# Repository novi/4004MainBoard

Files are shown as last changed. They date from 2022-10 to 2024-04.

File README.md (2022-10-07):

[周辺回路(ROM, IO)](https://github.com/novi/4004Peripheral)

TODO:

* たまにリセットが効かないことがある(手動リセットすること)
* バッファドライバの改善

## See Also

* [jim11662418/4004-SBC](https://github.com/jim11662418/4004-SBC)
* [MCS-4 Test Boards for Sale](https://www.cpushack.com/mcs-4-test-boards-for-sale/)
* [Intel 4004 — 50th Anniversary Project](https://www.4004.com)
* [Intel 4004 system](http://dangerousprototypes.com/forum/index.php?topic=4721.0)
* [MCS-4](http://www.st.rim.or.jp/~nkomatsu/intel4bit/i4004.html)
* [佐野正博「世界最初のマイクロプロセッサ Intel 4004」](https://www.sanosemi.com/document/Intel_4004_Ver4-2.pdf)
* [Intel 4004の回路図を読む](http://www.gc-net.jp/omiokone/mcs4/index.htm)
* [マイクロプロセッサ 4004 の開発](https://www.shmj.or.jp/dev_story/pdf/develop43.pdf)

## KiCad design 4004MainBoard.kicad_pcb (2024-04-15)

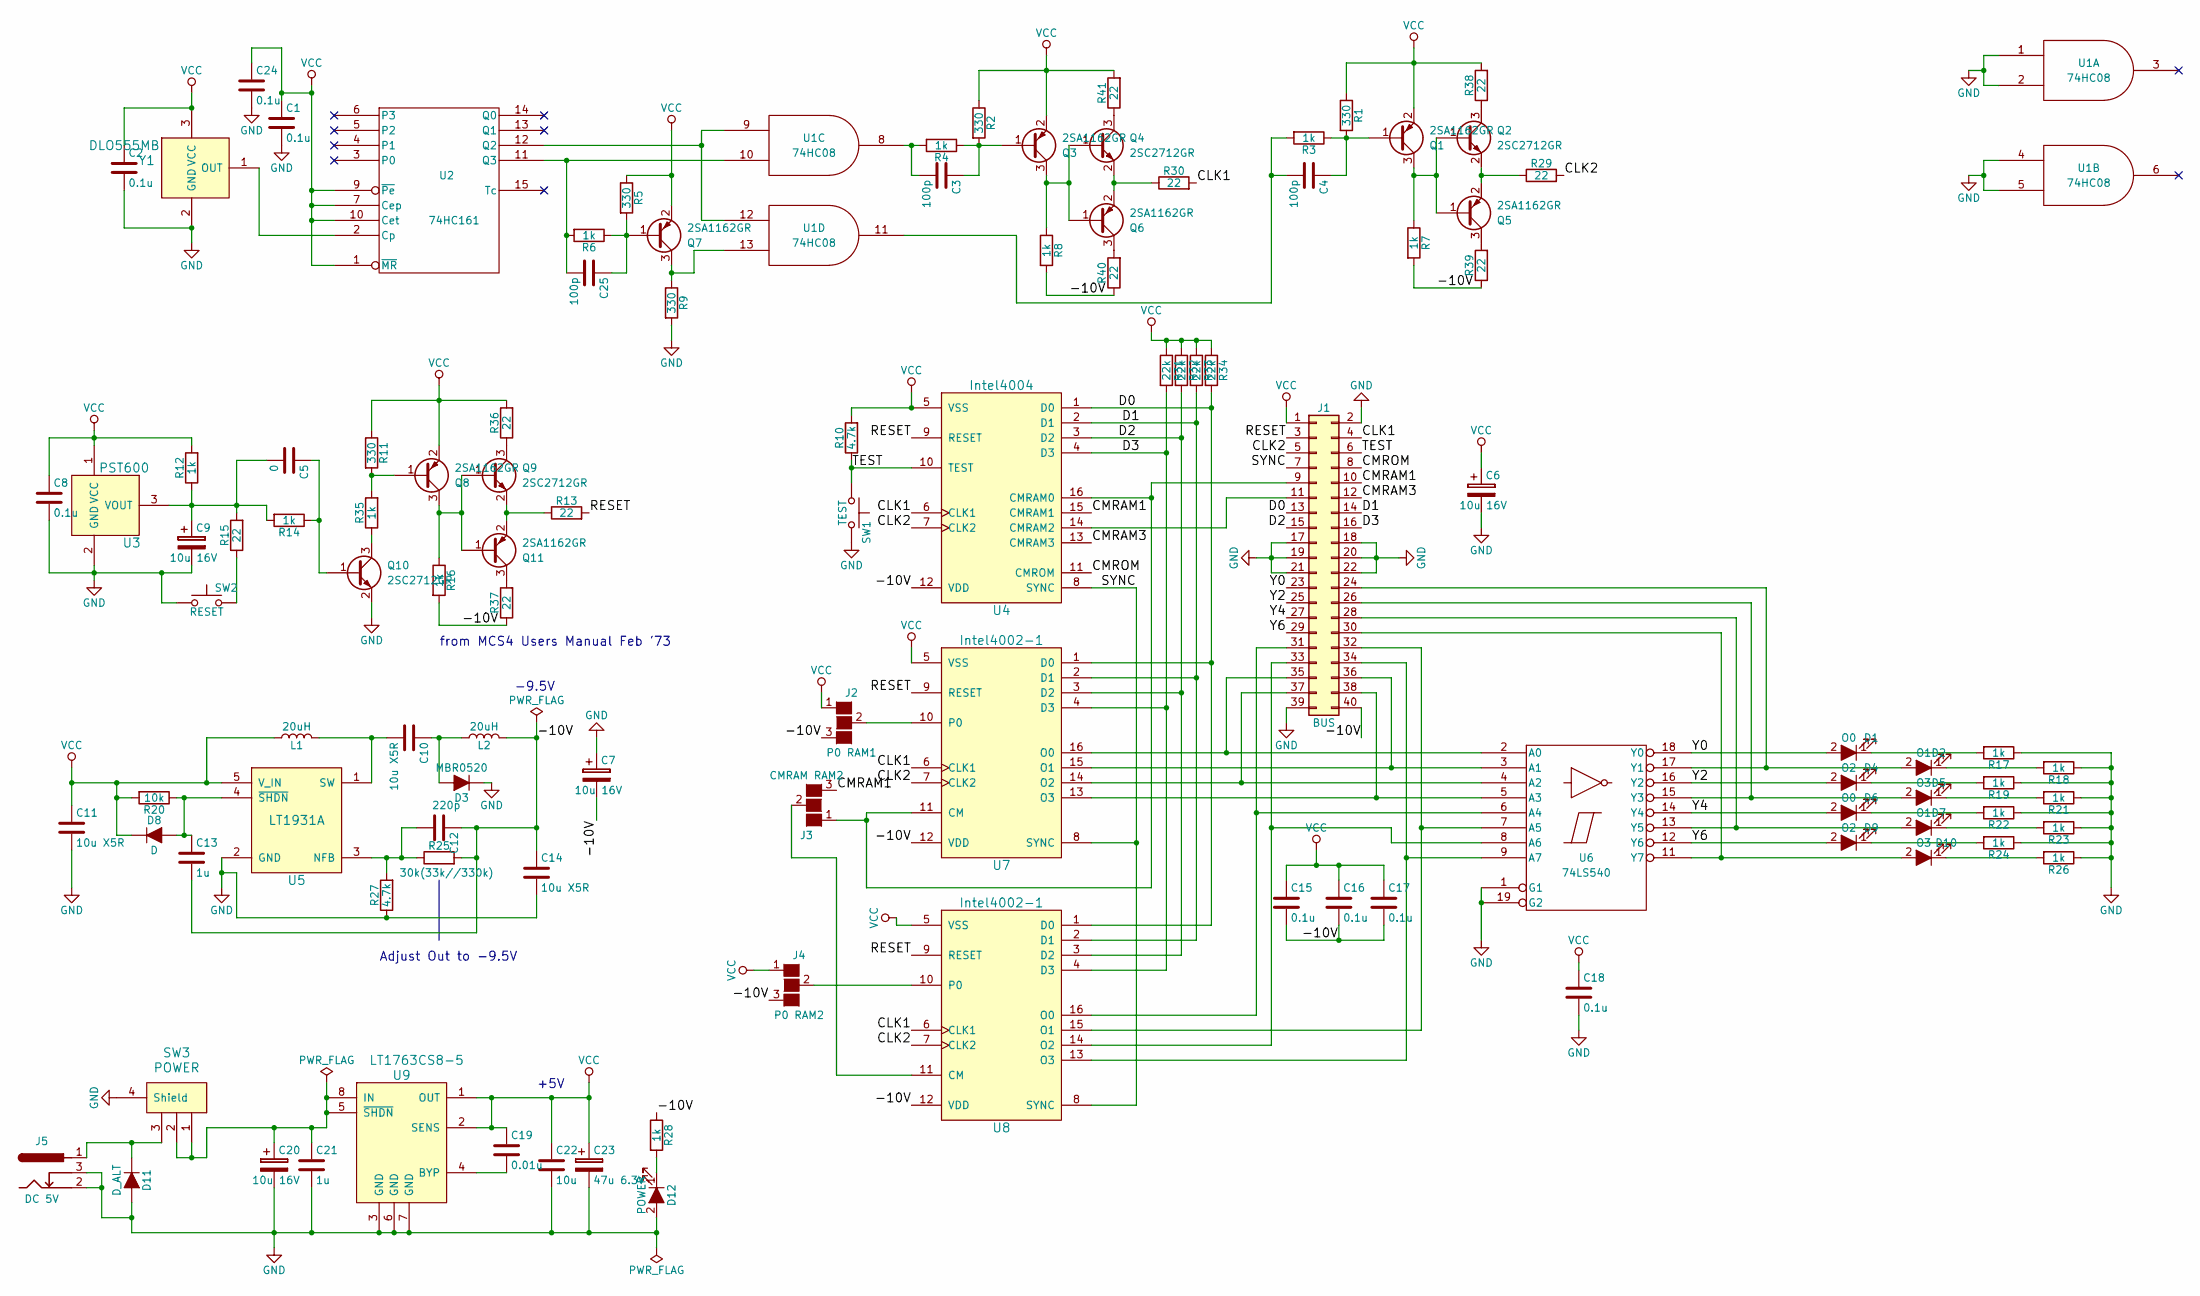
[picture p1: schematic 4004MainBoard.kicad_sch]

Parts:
C1, C2, C8, C15, C16, C17, C18, C24: 0.1u; C_0603_1608Metric_Pad1.08x0.95mm_HandSolder
C3, C4, C25: 100p; C_0603_1608Metric_Pad1.08x0.95mm_HandSolder
C5: 0; C_0603_1608Metric_Pad1.08x0.95mm_HandSolder
C6, C7, C9, C20: 10u 16V; CP_Elec_4x4.5
C10, C11, C14: 10u X5R; C_1206_HandSoldering
C12: 220p; C_0603_1608Metric_Pad1.08x0.95mm_HandSolder
C13, C21: 1u; C_0603_1608Metric_Pad1.08x0.95mm_HandSolder
C19: 0.01u; C_0603_1608Metric_Pad1.08x0.95mm_HandSolder
C22: 10u; C_1206_HandSoldering
C23: 47u 6.3V; CP_Elec_5x5.8
D1, D6: O0; LED_0603_HandSoldering
D2, D7: O1; LED_0603_HandSoldering
D3: MBR0520; D_SOD-123_HandSoldering
D4, D9: O2; LED_0603_HandSoldering
D5, D10: O3; LED_0603_HandSoldering
D8: D; D_SOD-123_HandSoldering
D11: D_ALT; D_SOD-123_HandSoldering
D12: POWER; LED_0603_HandSoldering
J1: BUS; Pin_Header_Straight_2x20_Pitch2.54mm
J2: P0 RAM1; GS3
J3: CMRAM RAM2; GS3
J4: P0 RAM2; GS3
J5: DC 5V; DC_JACK_MJ-179PH
L1, L2: 20uH; Choke_SMD_10.4x10.4_H4.8
Q1, Q3, Q5, Q6, Q7, Q8, Q11: 2SA1162GR; SC-59_Handsoldering
Q2, Q4, Q9, Q10: 2SC2712GR; SC-59_Handsoldering
R1, R2, R5, R9, R11: 330; R_0603_1608Metric_Pad0.98x0.95mm_HandSolder
R3, R4, R6, R7, R8, R12, R14, R16, R17, R18, R19, R21, R22, R23, R24, R26, R28, R35: 1k; R_0603_1608Metric_Pad0.98x0.95mm_HandSolder
R10, R27: 4.7k; R_0603_1608Metric_Pad0.98x0.95mm_HandSolder
R13, R15, R29, R30, R36, R37, R38, R39, R40, R41: 22; R_0603_1608Metric_Pad0.98x0.95mm_HandSolder
R20: 10k; R_0603_1608Metric_Pad0.98x0.95mm_HandSolder
R25: 30k(33k//330k); R_0603_1608Metric_Pad0.98x0.95mm_HandSolder
R31, R32, R33, R34: 22k; R_0603_1608Metric_Pad0.98x0.95mm_HandSolder
SW1: TEST; SW_PUSH_6mm
SW2: RESET; SW_PUSH_6mm
SW3: POWER; ToggleSW_MS-612A_RI
U1: 74HC08; SOIC-14_3.9_5.3x8.7mm_P1.27mm
U2: 74HC161; SOIC-16_3.9_5.3x10.2mm_P1.27mm
U3: PST600; TO-92_Inline_Wide
U4: Intel4004; DIP-16_W7.62mm_Socket
U5: LT1931A; TSOT-23-5_HandSoldering
U6: 74LS540; SOIC-20W_7.5x12.8mm_Pitch1.27mm
U7, U8: Intel4002-1; DIP-16_W7.62mm_Socket
U9: LT1763CS8-5; SOIC-8_3.9x4.9mm_Pitch1.27mm
Y1: DLO555MB; TO-92_Inline_Wide

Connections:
/-10V: C7.2, C12.1, C13.2, C14.1, C15.2, C16.2, C17.2, J1.40, J2.3 (G3), J4.3 (G3), L2.2, R7.2, R8.2, R16.2, R25.2, R28.1, R37.1, R39.1, R40.1, U4.12 (VDD), U7.12 (VDD), U8.12 (VDD)
/CLK1: J1.4, R30.2, U4.6 (CLK1), U7.6 (CLK1), U8.6 (CLK1)
/CLK2: J1.5, R29.2, U4.7 (CLK2), U7.7 (CLK2), U8.7 (CLK2)
/CMRAM1: J1.10, J3.3 (G3), U4.15 (CMRAM1)
/CMRAM3: J1.12, U4.13 (CMRAM3)
/CMROM: J1.8, U4.11 (CMROM)
/D0: J1.13, R34.2, U4.1 (D0), U7.1 (D0), U8.1 (D0)
/D1: J1.14, R33.2, U4.2 (D1), U7.2 (D1), U8.2 (D1)
/D2: J1.15, R32.2, U4.3 (D2), U7.3 (D2), U8.3 (D2)
/D3: J1.16, R31.2, U4.4 (D3), U7.4 (D3), U8.4 (D3)
/RESET: J1.3, R13.2, U4.9 (RESET), U7.9 (RESET), U8.9 (RESET)
/SYNC: J1.7, U4.8 (SYNC), U7.8 (SYNC), U8.8 (SYNC)
/TEST: J1.6, R10.1, SW1.1, U4.10 (TEST)
/Y0: D1.2 (A), J1.23, U6.18 (Y0)
/Y2: D4.2 (A), J1.25, U6.16 (Y2)
/Y4: D6.2 (A), J1.27, U6.14 (Y4)
/Y6: D9.2 (A), J1.29, U6.12 (Y6)
GND: C1.2, C2.2, C6.2, C7.1, C8.2, C9.2, C11.2, C14.2, C18.2, C20.2, C21.2, C22.2, C23.2, C24.2, D3.1 (K), D11.2 (A), D12.2 (A), J1.2, J1.17, J1.18, J1.19, J1.20, J1.21, J1.22, J1.39, J5.2, J5.3, Q10.2 (E), R9.2, R17.1, R18.1, R19.1, R21.1, R22.1, R23.1, R24.1, R26.1, R27.1, SW1.2, SW2.1, SW3.4 (Shield), U1.1, U1.2, U1.4, U1.5, U1.7 (GND), U2.8 (GND), U3.2 (GND), U5.2 (GND), U6.1 (G1), U6.10 (GND), U6.19 (G2), U9.3 (GND), U9.6 (GND), U9.7 (GND), Y1.2 (GND)
unnamed: C3.2, R4.2, U1.8
unnamed: C4.2, R3.2, U1.11
unnamed: D1.1 (K), R17.2
unnamed: D2.2 (A), J1.24, U6.17 (Y1)
unnamed: D2.1 (K), R18.2
unnamed: C10.1, D3.2 (A), L2.1
unnamed: D4.1 (K), R19.2
unnamed: D5.2 (A), J1.26, U6.15 (Y3)
unnamed: D5.1 (K), R21.2
unnamed: D6.1 (K), R22.2
unnamed: D7.2 (A), J1.28, U6.13 (Y5)
unnamed: D7.1 (K), R23.2
unnamed: C13.1, D8.2 (A), R20.1, U5.4 (~SHDN)
unnamed: D9.1 (K), R24.2
unnamed: D10.2 (A), J1.30, U6.11 (Y7)
unnamed: D10.1 (K), R26.2
unnamed: D11.1 (K), J5.1, SW3.3
unnamed: D12.1 (K), R28.2
unnamed: J1.9, J3.1 (G1), U4.16 (CMRAM0), U7.11 (CM)
unnamed: J1.11, U4.14 (CMRAM2)
unnamed: J1.31, U6.6 (A4), U8.16 (O0)
unnamed: J1.32, U6.7 (A5), U8.15 (O1)
unnamed: J1.33, U6.8 (A6), U8.14 (O2)
unnamed: J1.34, U6.9 (A7), U8.13 (O3)
unnamed: J1.35, U6.2 (A0), U7.16 (O0)
unnamed: J1.36, U6.3 (A1), U7.15 (O1)
unnamed: J1.37, U6.4 (A2), U7.14 (O2)
unnamed: J1.38, U6.5 (A3), U7.13 (O3)
unnamed: J2.2 (G2), U7.10 (P0)
unnamed: J3.2 (G2), U8.11 (CM)
unnamed: J4.2 (G2), U8.10 (P0)
unnamed: C4.1, Q1.1 (B), R1.2, R3.1
unnamed: Q1.3 (C), Q2.1 (B), Q5.1 (B), R7.1
unnamed: Q2.3 (C), R38.1
unnamed: Q2.2 (E), Q5.2 (E), R29.1
unnamed: C3.1, Q3.1 (B), R2.2, R4.1
unnamed: Q3.3 (C), Q4.1 (B), Q6.1 (B), R8.1
unnamed: Q4.3 (C), R41.1
unnamed: Q4.2 (E), Q6.2 (E), R30.1
unnamed: Q5.3 (C), R39.2
unnamed: Q6.3 (C), R40.2
unnamed: C25.1, Q7.1 (B), R5.2, R6.1
unnamed: Q7.3 (C), R9.1, U1.13
unnamed: Q8.1 (B), R11.2, R35.2
unnamed: Q9.3 (C), R36.1
unnamed: C5.1, Q10.1 (B), R14.1
unnamed: Q10.3 (C), R35.1
unnamed: Q8.3 (C), Q9.1 (B), Q11.1 (B), R16.1
unnamed: Q11.3 (C), R37.2
unnamed: Q9.2 (E), Q11.2 (E), R13.1
unnamed: R15.1, SW2.2
unnamed: U2.2 (Cp), Y1.1 (OUT)
unnamed: U1.9, U1.12, U2.12 (Q2)
unnamed: C25.2, R6.2, U1.10, U2.11 (Q3)
unnamed: C5.2, C9.1, R12.1, R14.2, R15.2, U3.3 (VOUT)
unnamed: C12.2, R25.1, R27.2, U5.3 (NFB)
unnamed: C10.2, L1.2, U5.1 (SW)
unnamed: C19.2, U9.4 (BYP)
unnamed: C20.1, C21.1, SW3.1, SW3.2, U9.5 (~SHDN), U9.8 (IN)
VCC: C1.1, C2.1, C6.1, C8.1, C11.1, C15.1, C16.1, C17.1, C18.1, C19.1, C22.1, C23.1, C24.1, D8.1 (K), J1.1, J2.1 (G1), J4.1 (G1), L1.1, Q1.2 (E), Q3.2 (E), Q7.2 (E), Q8.2 (E), R1.1, R2.1, R5.1, R10.2, R11.1, R12.2, R20.2, R31.1, R32.1, R33.1, R34.1, R36.2, R38.2, R41.2, U1.14 (VCC), U2.1 (~MR), U2.7 (Cep), U2.9 (~Pe), U2.10 (Cet), U2.16 (VCC), U3.1 (VCC), U4.5 (VSS), U5.5 (V_IN), U6.20 (VCC), U7.5 (VSS), U8.5 (VSS), U9.1 (OUT), U9.2 (SENS), Y1.3 (VCC)

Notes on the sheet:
Adjust Out to -9.5V
+5V
from MCS4 Users Manual Feb '73
-9.5V

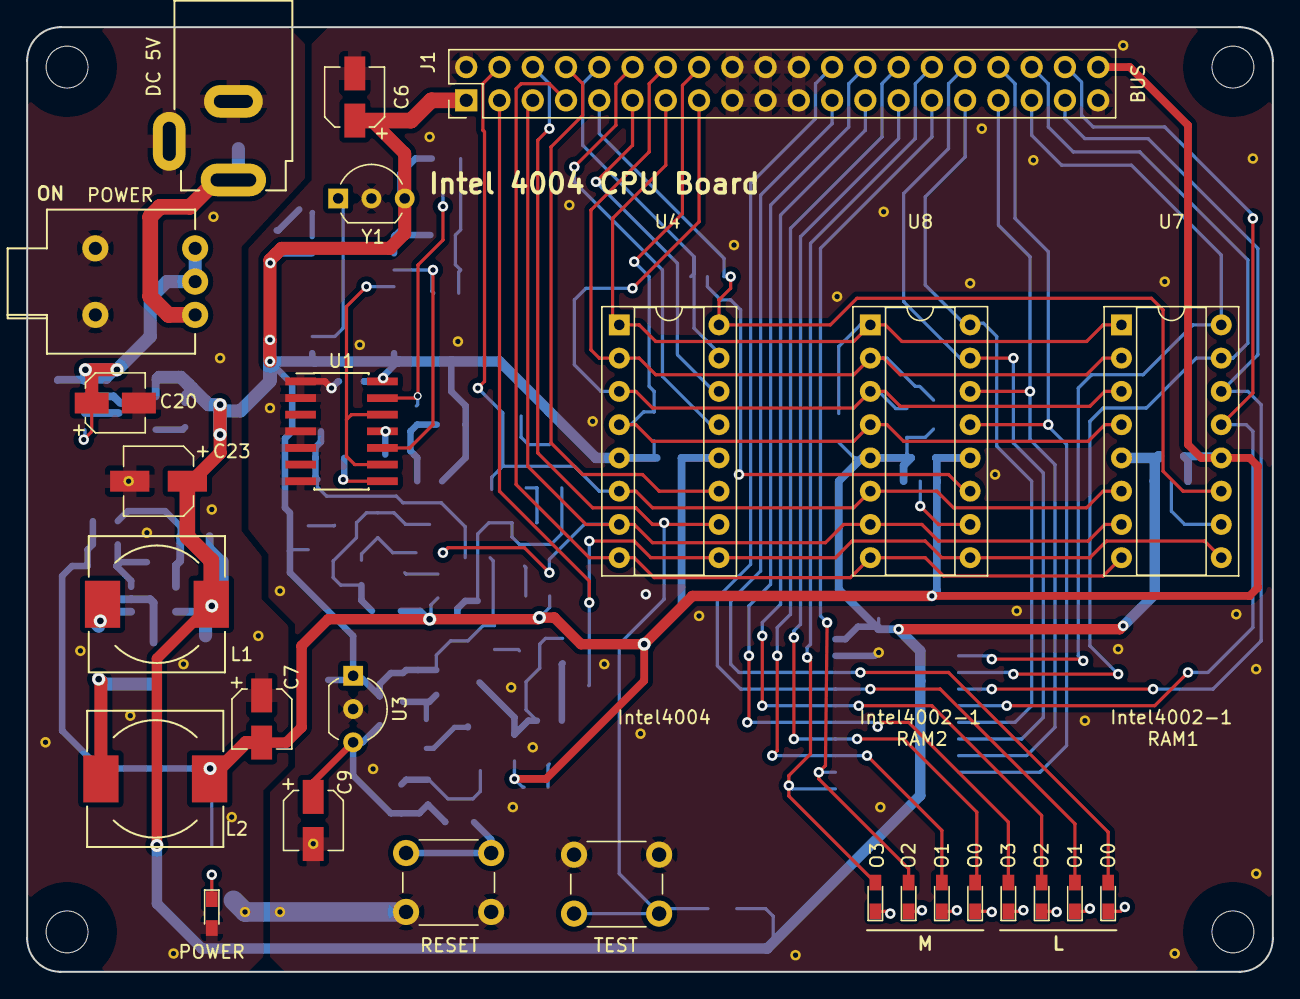
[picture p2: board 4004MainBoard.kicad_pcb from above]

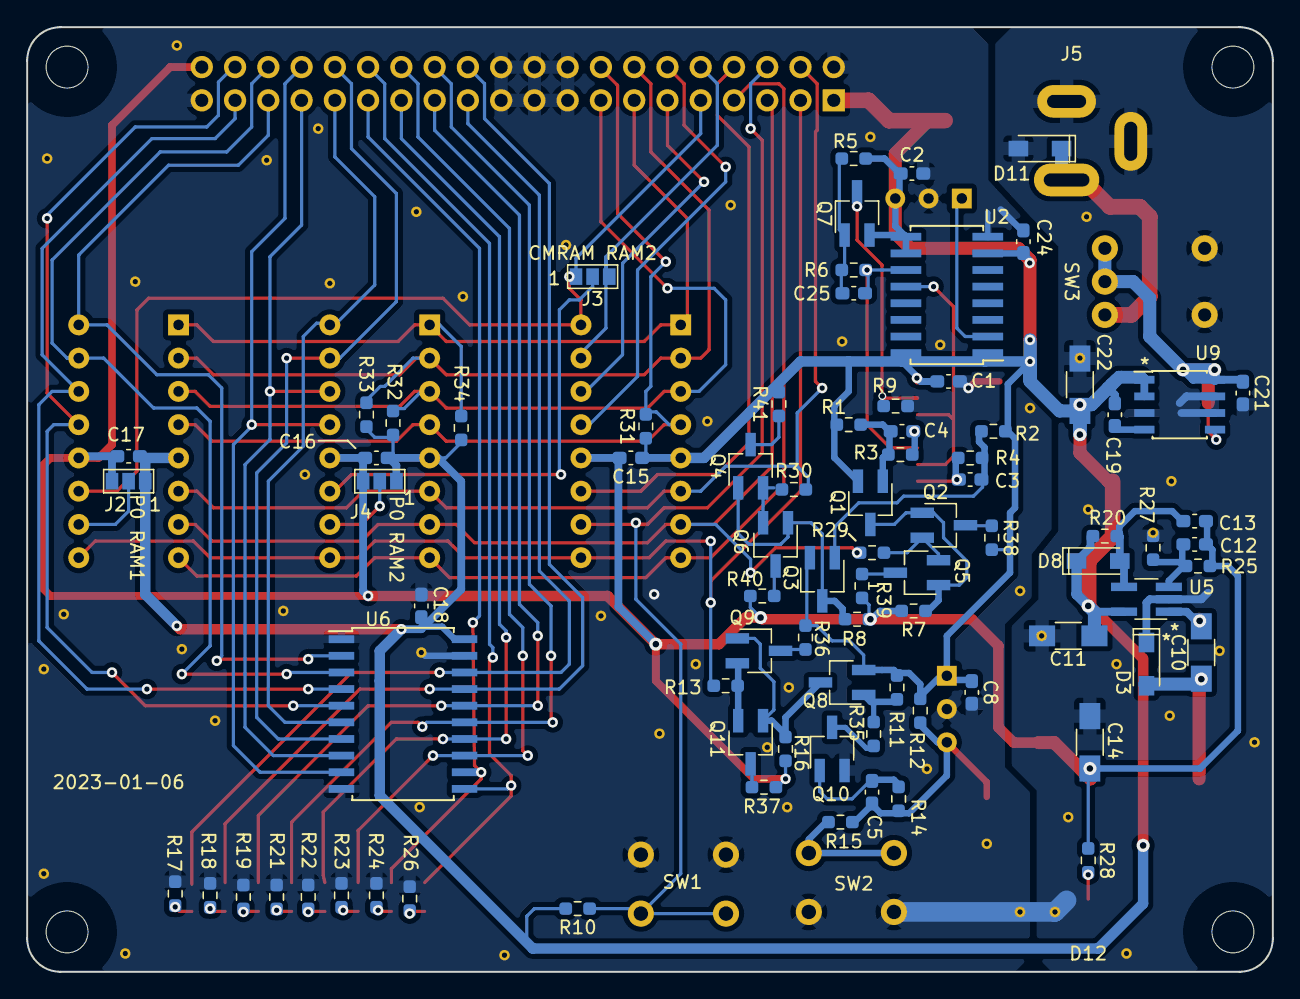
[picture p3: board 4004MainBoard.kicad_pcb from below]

Board: 2 copper layers, 95.1 x 72.1 mm, 109 parts (82 on the bottom side), 78 nets.

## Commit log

2018-01-21 回路を実装
    [4004MainBoard.kicad_pcb, 4004MainBoard.sch]
2018-05-03 パターンを実装
    [4004MainBoard.kicad_pcb, 4004MainBoard.sch]
2018-05-04 パターン修正 ビア実装
    [4004MainBoard.kicad_pcb, 4004MainBoard.sch]
2018-05-13 回路修正 シルク修正
    [4004MainBoard.kicad_pcb, 4004MainBoard.sch]
2018-06-24 電源電圧調整 基板修正
    [4004MainBoard.kicad_pcb, 4004MainBoard.sch]
2021-03-12 整理時コミット
    [4004MainBoard.kicad_pcb]
2022-10-07 migrate to KiCad 6
    [4004MainBoard.kicad_sch, 4004MainBoard.sch]
2024-01-06 migrate to KiCad 7
    [4004MainBoard.kicad_pcb, 4004MainBoard.kicad_sch]
2024-04-15 update descrete buffer add notes
    [4004MainBoard.kicad_pcb, 4004MainBoard.kicad_sch]
